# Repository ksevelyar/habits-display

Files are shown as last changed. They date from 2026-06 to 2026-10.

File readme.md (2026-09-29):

# Habits Display

## What it does

On boot the device joins the Wi-Fi network, syncs time over NTP, and opens a WebSocket connection to the notifications server. It authenticates with a JWT, then receives task events as they arrive and renders the latest notification on the display: one word per line, scaled to fill the screen.

## Build & Flash
```
nix develop

cargo run --release
   Compiling habits-display v0.1.0 (/home/ksevelyar/code/habits-display)
    Finished `release` profile [optimized + debuginfo] target(s) in 3.19s
     Running `probe-rs run --chip=esp32c3 --preverify --always-print-stacktrace --no-location target/riscv32imc-unknown-none-elf/release/habits-display`
      Erasing ✔ 100% [####################] 640.00 KiB @ 643.39 KiB/s (took 1s)
  Programming ✔ 100% [####################] 328.90 KiB @  83.70 KiB/s (took 4s)           Finished in 5.73s
[INFO ] Embassy initialized!
[INFO ] starting wifi
[INFO ] IPv4: DOWN
[INFO ] start connection task
[INFO ] About to connect...
[INFO ] link_up = true
[INFO ] IPv4: DOWN
[INFO ] Connected to "fellowship-of-the-ring-2" (channel: 4)
[INFO ] ws: network ready
[INFO ] NTP: got IP
[INFO ] Rtc after update:1780660466
[INFO ] ws: connected
[INFO ] ws: handshake sent
[INFO ] ws: handshake ok
[INFO ] ws: {"event":"UserAuthenticated","user":{"email":"ksevelyar@gmail.com","id":1,"timezone":"Europe/Moscow"}}
[INFO ] ws: ping
[INFO ] ws: ping
[INFO ] ws: task: debug 🐗 piglet
[INFO ] ws: ping
[INFO ] ws: ping
[INFO ] ws: task: debug 🐗 piglet
```

## udev setup for ESP32-C3 with probe-rs

```nix
services.udev.extraRules = ''
  # NOTE: esp32c3
  SUBSYSTEM=="usb", ATTR{idVendor}=="303a", ATTR{idProduct}=="1001", MODE="0660", GROUP="dialout"
'';
```

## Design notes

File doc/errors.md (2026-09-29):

# Errors

## Contract
Contexts are the device's public API. Their fallible functions return `Result<T, AppError>`. Raw errors (`esp_radio::wifi::WifiError`, `edge_ws::io::Error`, `embedded_tls::Error`) stay inside contexts as implementation details and are logged at the failure site via `defmt::error!`.

## Types
`AppError` outcomes:

* `Config(&'static str)`: build-time misconfiguration, carries the offending setting name
* `Network(&'static str)`: connection could not be established or was lost, carries the failed stage, e.g. `"tcp connection failed"`
* `Timeout`: no progress beyond our timeout limit, treated as dead

## Rules
* Failure sites log the raw error and propagate the coarse `AppError` variant

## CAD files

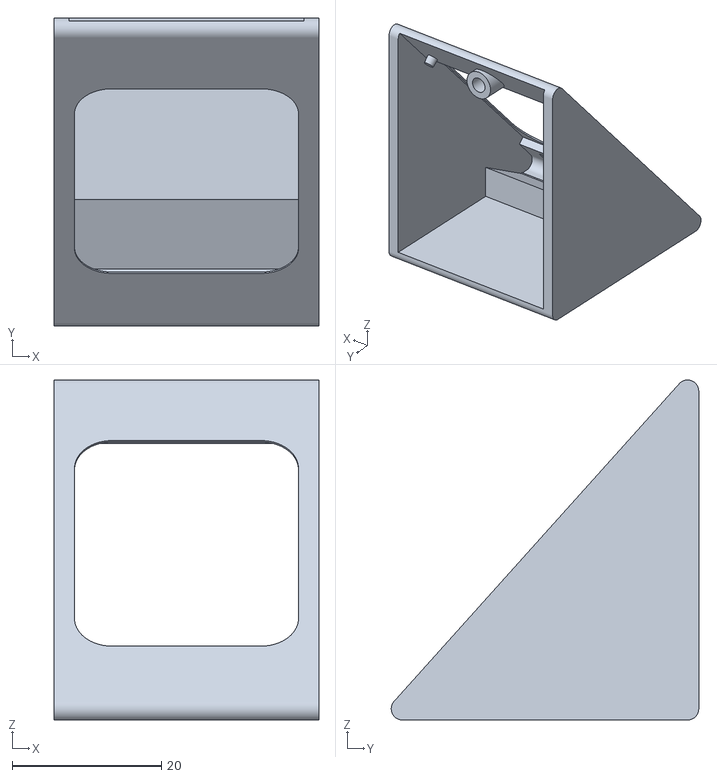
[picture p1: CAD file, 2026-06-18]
case/case.stl
35.5 x 41.2 x 45.5

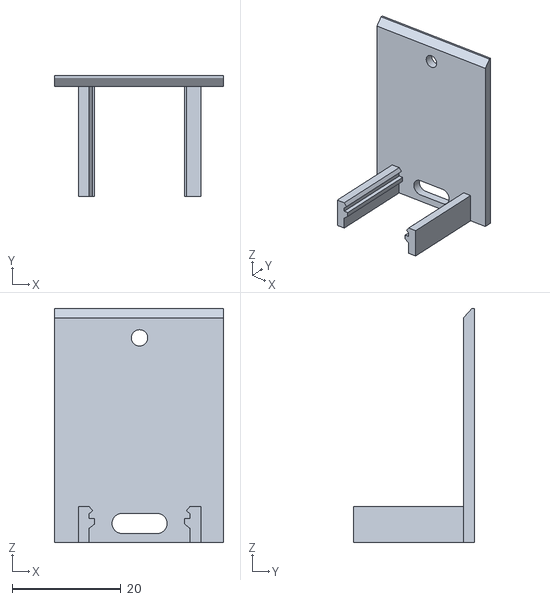
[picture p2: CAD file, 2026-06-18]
case/lid.stl
31.1 x 22.2 x 43.0

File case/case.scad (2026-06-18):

include <mixin.scad>;

display_pcb_length = 39;
display_pcb_width = display_width;

display_lcd_length = 37;
display_lcd_width = 30;

pcb_cutout_z = 0.7;
pcb_cutout_h = 3.1;
lcd_cutout_z = -0.1;
lcd_cutout_h = 1;

screw_inset = 2.1;
screw_top_d = 2;
screw_bot_d = 1.7;
screw_h = 3;

module display_cutout() {
  translate(
    [
      (case_width - display_pcb_width) / 2,
      (case_length - display_pcb_length) / 2,
      pcb_cutout_z,
    ]
  ) cube([display_pcb_width, display_pcb_length, pcb_cutout_h]);

  translate(
    [
      (case_width - display_lcd_width) / 2,
      (case_length - display_lcd_length) / 2,
      lcd_cutout_z,
    ]
  )
    rounded_box(size=[display_lcd_width, display_lcd_length, lcd_cutout_h], r=5);

  translate(
    [
      (case_width - display_pcb_width) / 2 + 3.5,
      (case_length - display_pcb_length) / 2 - 3.5,
      pcb_cutout_z,
    ]
  ) cube([display_lcd_width - 7, 2, pcb_cutout_h]);
}

module mcu_stopper() {
  difference() {
    translate([-case_width, case_length - 16.1 - wall*3 - esp32c3_length, wall - 0.1]) cube([case_width, 10, 6]);

    translate([-case_width, case_length - 16 - wall*3 - esp32c3_length, wall])
      rotate([30, 0, 0]) cube([case_width, 12, 6]);
  }
}

module base() {
  difference() {
    rounded_wedge(
      length=case_width,
      width=case_base_width,
      height=case_base_height,
      r=1.5
    );

    translate([-wall, wall * 2, wall]) rounded_wedge(
        length=display_width,
        width=case_base_width,
        height=case_base_height,
        r=1.5
      );

    translate([0, 2, 5]) rotate([90 + 42, 0, 180]) display_cutout();
  }

  translate([0, 2, 5]) rotate([90 + 42, 0, 180]) {
      translate([case_width - screw_inset - wall - 0.45, case_length - screw_inset - wall, 0.5]) cylinder(screw_h, d1=screw_top_d, d2=screw_bot_d);
      translate([wall + screw_inset + 0.45, case_length - screw_inset - wall, 0.5]) cylinder(screw_h, d1=screw_top_d, d2=screw_bot_d);
    }

  mcu_stopper();

  intersection() {
    translate([-wall, wall * 2, wall]) rounded_wedge(
        length=display_width,
        width=case_base_width,
        height=case_base_height,
        r=1.5
      );
    translate([-display_width / 2 - wall, display_length - 17, height * 1.65]) rotate([90, 0, 180]) leg(9);
  }
}
base();

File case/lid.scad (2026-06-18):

include <mixin.scad>;

module lid() {
  translate([-display_width / 2 - wall, 0, wall]) esp32c3_mini_rails();

  difference() {
    intersection() {
      translate([-wall, wall * 2, wall]) rounded_wedge(
          length=display_width - 0.1,
          width=case_base_width - 0.1,
          height=case_base_height - 0.1,
          r=1.5
        );
      translate([-display_width - wall - 0.1, case_base_width - wall, 0]) cube([display_width - 0.2, wall, case_length - 6]);
    }

    translate([-display_width / 2 - wall, display_length, 5.5]) type_c_cutout();

    translate([-display_width / 2 - wall, display_length - 10, height * 1.65]) rotate([90, 0, 180]) cylinder(10, d=3);
  }
}

lid();

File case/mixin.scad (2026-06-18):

wall = 2;
display_length = 47;
display_width = 31.5;
esp32c3_width = 18.5;
esp32c3_length = 22;
height = 24;

case_width = display_width + wall * 2;
case_length = display_length + wall * 2;
case_base_width = 41.2;
case_base_height = 39.55;

$fn = 128;

module rail_side(half_width, length, y) {
  translate([-half_width - 2, y, 0]) cube([2, length, 6.6]);
  hull() {
    translate([-half_width - 0.15, y, 2.5]) rotate([0, -40, 0]) cube([1.5, length, 1]);
    translate([-half_width - 0.5, y, 3.4]) cube([1.5, length, 1]);
  }
  translate([-half_width - 0.35, y, 5]) rotate([0, -40, 0]) cube([1.3, length, 1]);
}

module rail(half_width, length, y) {
  rail_side(half_width, length, y);
  mirror([1, 0, 0]) rail_side(half_width, length, y);
}

module esp32c3_mini_rails() {
  rail(esp32c3_width / 2, esp32c3_length, 19);
}

module type_c_cutout() {
  rotate([90, 0, 0])
    hull() {
      translate([-3.2, 0, 0]) cylinder(h=10, d=3.7);
      translate([3.2, 0, 0]) cylinder(h=10, d=3.7);
    }
}

module leg(leg_height) {
  difference() {
    cylinder(h=leg_height, d=5.1);
    translate([0, 0, -0.1]) cylinder(h=leg_height + 1, d=2.7);
  }
}

module rounded_box(size = [10, 10, 5], r) {
  translate([size[0] / 2, size[1] / 2, 0])
    linear_extrude(height = size[2])
      offset(r = r)
        square([size[0] - 2 * r, size[1] - 2 * r], center = true);
}

module rounded_wedge(length, width, height, r = 1.5) {
  translate([0, 0, r * 2]) hull() {
      translate([0, r, -r])
        rotate([0, 90, 180])
          cylinder(h=length, d=r * 2);

      translate([0, width - r, -r])
        rotate([0, 90, 180])
          cylinder(h=length, d=r * 2);

      translate([0, width - r, height + r])
        rotate([0, 90, 180])
          cylinder(h=length, d=r * 2);
    }
}

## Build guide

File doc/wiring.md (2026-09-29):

# Wiring
### Display -> ESP32-C3 Super Mini
* BLK -> 3V3
* CS  -> GPIO7
* DC  -> GPIO8
* RES -> GPIO9
* SDA -> GPIO6 (MOSI)
* SCL -> GPIO4 (SCK)
* VCC -> 3V3
* GND -> GND

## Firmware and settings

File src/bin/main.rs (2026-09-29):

#![no_std]
#![no_main]

use esp_alloc as _;
use esp_hal::{
    clock::CpuClock,
    rng::Rng,
    rtc_cntl::Rtc,
    spi::{
        Mode,
        master::{Config, Spi},
    },
    time::Rate,
    timer::timg::TimerGroup,
};
use habits_display::{display, time, websocket, wifi};
use panic_rtt_target as _;

use defmt::info;
use embassy_executor::Spawner;
use embassy_time::{Duration, Timer};

extern crate alloc;

esp_bootloader_esp_idf::esp_app_desc!();

#[esp_rtos::main]
async fn main(spawner: Spawner) -> ! {
    rtt_target::rtt_init_defmt!();

    let config = esp_hal::Config::default().with_cpu_clock(CpuClock::max());
    let peripherals = esp_hal::init(config);
    let rtc = Rtc::new(peripherals.LPWR);

    esp_alloc::heap_allocator!(#[esp_hal::ram(reclaimed)] size: 66320);

    let timg0 = TimerGroup::new(peripherals.TIMG0);
    let sw_interrupt =
        esp_hal::interrupt::software::SoftwareInterruptControl::new(peripherals.SW_INTERRUPT);
    esp_rtos::start(timg0.timer0, sw_interrupt.software_interrupt0);
    info!("Embassy initialized!");

    let (controller, stack, runner) = wifi::init(peripherals.WIFI);

    let sclk = peripherals.GPIO4;
    let mosi = peripherals.GPIO6;

    let cs = peripherals.GPIO7;
    let dc = peripherals.GPIO8;
    let rst = peripherals.GPIO9;

    let spi = Spi::new(
        peripherals.SPI2,
        Config::default()
            .with_frequency(Rate::from_khz(40000))
            .with_mode(Mode::_0),
    )
    .unwrap()
    .with_sck(sclk)
    .with_mosi(mosi);

    let rng = Rng::new();

    spawner.spawn(wifi::connection(controller).unwrap());
    spawner.spawn(wifi::net_task(runner).unwrap());
    spawner.spawn(time::task(rtc, stack).unwrap());
    spawner.spawn(websocket::task(stack, rng).unwrap());
    spawner.spawn(display::task(spi, cs, dc, rst).unwrap());

    loop {
        Timer::after(Duration::from_secs(3600)).await;
    }
}

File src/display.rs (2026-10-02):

use core::convert::Infallible;

use defmt::error;
use embassy_time::{Duration, with_timeout};
use embedded_graphics::{
    draw_target::DrawTarget,
    geometry::{Point, Size},
    mono_font::{MonoTextStyle, ascii::FONT_10X20},
    pixelcolor::Rgb565,
    prelude::*,
    primitives::Rectangle,
    text::{Alignment, Text, TextStyle},
};
use embedded_hal_bus::spi::ExclusiveDevice;
use esp_hal::{
    Blocking,
    delay::Delay,
    gpio::{Level, Output, OutputConfig},
    peripherals::GPIO7,
    peripherals::GPIO8,
    peripherals::GPIO9,
    spi::master::Spi,
};
use mipidsi::{
    Builder, interface::SpiInterface, models::ST7789, options::ColorInversion,
    options::Orientation, options::Rotation,
};
use static_cell::StaticCell;

use crate::DISPLAY_CHANNEL;

static BUF: StaticCell<[u8; 512]> = StaticCell::new();

#[derive(Clone, Copy, PartialEq)]
struct Theme {
    background: Rgb565,
    foreground: Rgb565,
}

const DAY_THEME: Theme = Theme {
    background: Rgb565::new(16, 4, 20),
    foreground: Rgb565::new(63, 63, 63),
};

const NIGHT_THEME: Theme = Theme {
    background: Rgb565::new(0, 0, 0),
    foreground: Rgb565::new(18, 12, 2),
};

fn select_theme() -> Theme {
    let hour = crate::time::local_time().hour() as u8;
    let (day_start_hour, night_start_hour) = (8, 17);
    if (day_start_hour..night_start_hour).contains(&hour) {
        DAY_THEME
    } else {
        NIGHT_THEME
    }
}

struct ScaleView<'a, D>
where
    D: DrawTarget<Color = Rgb565>,
{
    parent: &'a mut D,
    scale: u32,
}

impl<D: DrawTarget<Color = Rgb565>> ScaleView<'_, D> {
    fn scaled_point(&self, point: Point) -> Point {
        Point::new(point.x * self.scale as i32, point.y * self.scale as i32)
    }

    fn scaled_pixels(
        origin: Point,
        scale: u32,
        color: Rgb565,
    ) -> impl Iterator<Item = Pixel<Rgb565>> {
        (0..scale * scale).map(move |offset| {
            Pixel(
                origin + Point::new((offset % scale) as i32, (offset / scale) as i32),
                color,
            )
        })
    }
}

impl<D: DrawTarget<Color = Rgb565>> DrawTarget for ScaleView<'_, D> {
    type Color = Rgb565;
    type Error = Infallible;

    fn draw_iter<I>(&mut self, pixels: I) -> Result<(), Self::Error>
    where
        I: IntoIterator<Item = Pixel<Rgb565>>,
    {
        for pixel in pixels {
            let origin = self.scaled_point(pixel.0);
            for scaled in Self::scaled_pixels(origin, self.scale, pixel.1) {
                let _ = self.parent.draw_iter([scaled]);
            }
        }
        Ok(())
    }

    fn fill_solid(&mut self, area: &Rectangle, color: Rgb565) -> Result<(), Self::Error> {
        let top_left = self.scaled_point(area.top_left);
        let scaled_size = Size::new(area.size.width * self.scale, area.size.height * self.scale);
        let _ = self
            .parent
            .fill_solid(&Rectangle::new(top_left, scaled_size), color);
        Ok(())
    }
}

impl<D: DrawTarget<Color = Rgb565>> Dimensions for ScaleView<'_, D> {
    fn bounding_box(&self) -> Rectangle {
        let box_ = self.parent.bounding_box();
        Rectangle::new(
            self.scaled_point(box_.top_left),
            Size::new(box_.size.width * self.scale, box_.size.height * self.scale),
        )
    }
}

#[embassy_executor::task]
pub async fn task(
    spi: Spi<'static, Blocking>,
    cs: GPIO7<'static>,
    dc: GPIO8<'static>,
    rst: GPIO9<'static>,
) {
    let mut delay = Delay::new();

    let cs = Output::new(cs, Level::High, OutputConfig::default());
    let dc = Output::new(dc, Level::Low, OutputConfig::default());
    let rst = Output::new(rst, Level::High, OutputConfig::default());

    let buf: &'static mut [u8; 512] = BUF.init([0u8; 512]);
    let device = ExclusiveDevice::new_no_delay(spi, cs).unwrap();
    let di = SpiInterface::new(device, dc, buf);

    let mut display = Builder::new(ST7789, di)
        .reset_pin(rst)
        .display_size(240, 300)
        .orientation(Orientation::new().rotate(Rotation::Deg90))
        .invert_colors(ColorInversion::Inverted)
        .init(&mut delay)
        .unwrap();

    let mut theme = select_theme();

    display.clear(theme.background).unwrap();

    let mut last_task: Option<heapless::String<256>> = None;

    loop {
        let phase_poll_interval = Duration::from_secs(60);
        let incoming = with_timeout(phase_poll_interval, DISPLAY_CHANNEL.receive())
            .await
            .ok();

        let next_theme = select_theme();
        if incoming.is_none() && next_theme == theme {
            continue;
        }
        theme = next_theme;

        last_task = incoming.or(last_task);

        let Some(task) = last_task.as_ref() else {
            continue;
        };

        display.clear(theme.background).unwrap();

        let style = MonoTextStyle::new(&FONT_10X20, theme.foreground);
        let text_style = TextStyle::with_alignment(Alignment::Center);

        let mut lines: heapless::Vec<heapless::String<32>, 8> = heapless::Vec::new();
        for word in task.split(' ') {
            let line: heapless::String<32> = word.chars().filter(char::is_ascii_graphic).collect();
            if line.is_empty() {
                continue;
            }
            if lines.push(line).is_err() {
                error!("display: too many words");
                break;
            }
        }

        if lines.is_empty() {
            continue;
        }

        let line_height = 40;
        let baseline_offset = 30;
        let line_count = lines.len() as i32;
        let block_top = (240 - line_count * line_height) / 2;

        let mut view = ScaleView {
            parent: &mut display,
            scale: 2,
        };
        for (index, line) in lines.iter().enumerate() {
            let baseline = (block_top + baseline_offset + index as i32 * line_height) / 2;
            if Text::with_text_style(line, Point::new(75, baseline), style, text_style)
                .draw(&mut view)
                .is_err()
            {
                error!("display: draw failed");
            }
        }
    }
}

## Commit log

2026-05-26 switch ci to nix
2026-06-15 add openscad case
    [case.scad, case.stl, lid.scad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]
2026-06-16 fix case geometry
    [case.scad, case.stl, lid.scad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]
2026-06-18 case fixes
    [case.scad, case.stl, lid.scad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]
2026-06-18 fix type c cutout
    [case.stl, lid.stl, mixin.scad]
2026-09-29 add doc for errors
    [main.rs]
